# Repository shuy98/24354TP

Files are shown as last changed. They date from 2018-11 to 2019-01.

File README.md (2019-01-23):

# Semi-Autonomous Omnidirectional Manipulation Robot 
Term project for course 24-354 Gadgetry: Sensors, Actuators, and Processors at Carnegine Mellon University.  
This is a team project by Shu You, Nikhila Vembu, and Hardik Singh.  
Any questions/comments or you want additional info please send me an email: shuy@andrew.cmu.edu 

## Description
We created a small, moveable, omnidirectional robot that will be controlled virtually using a Kinect. We will demonstrate control of the robot and the ability to accomplish a terrain manipulation task with the robot by using a series of arm/hand gestures to command the robot’s movement and use of its gripper. The task will consist of retrieving an object and returning it into and ending spot based on the way we direct it with our bodies. The robot will ideally have to navigate through a few obstacles and then reach a box which senses that the robot arrived with the object.

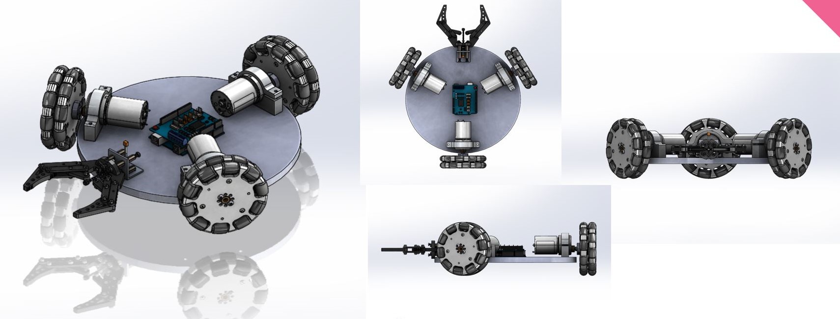
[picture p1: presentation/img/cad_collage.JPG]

*Fig 1. Robot CAD Image*

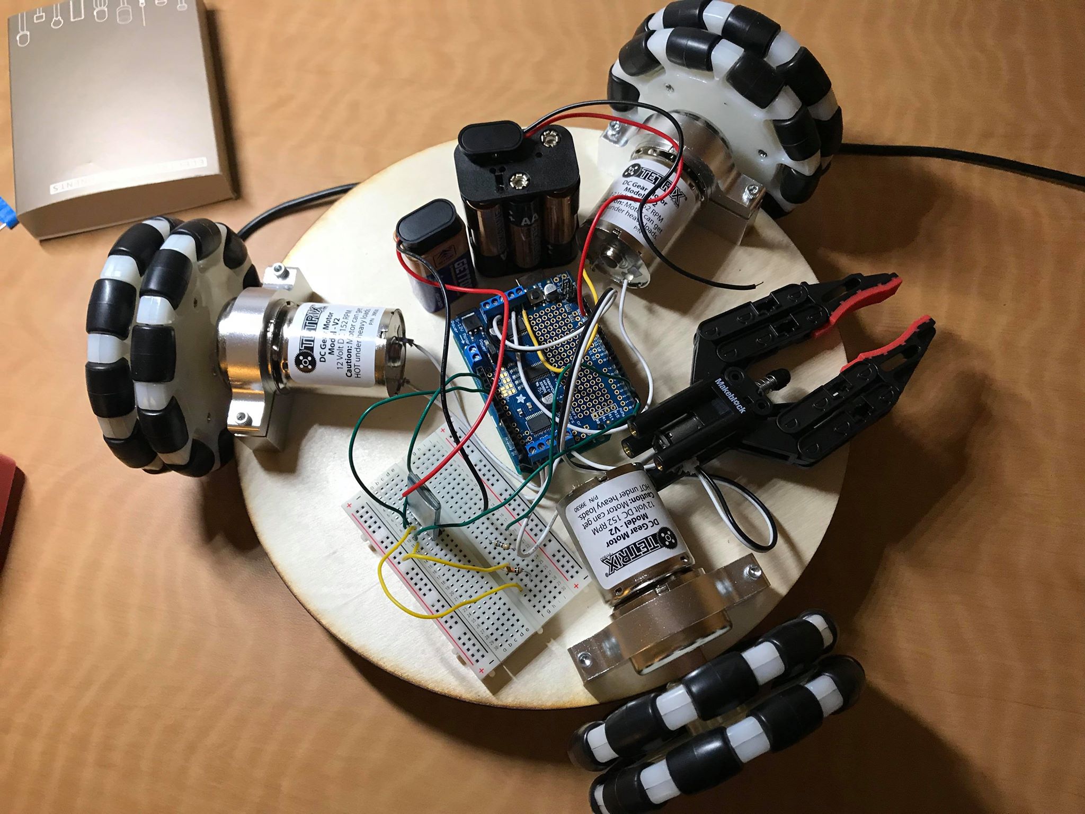
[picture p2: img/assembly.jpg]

*Fig 2. Robot Final Assembly*

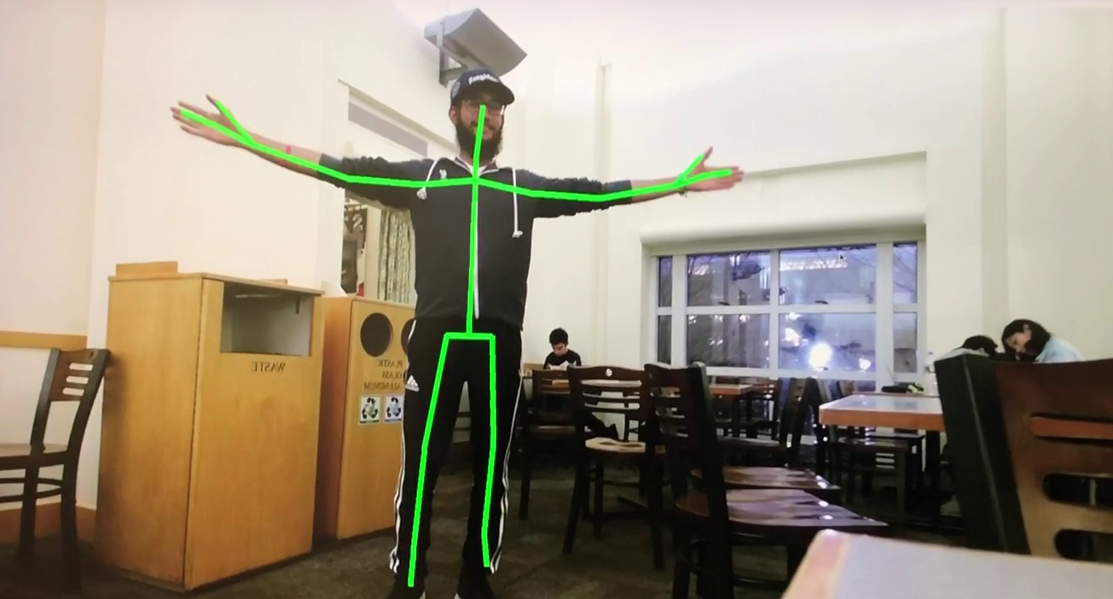
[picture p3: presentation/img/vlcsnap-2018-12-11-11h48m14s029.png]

*Fig 3. Kinect Control Interface*

## Problem Statement
We are aiming to display and test how well we can control unmanned robots and drones better with our bodies. 
Where "gaming controllers" are limited by their buttons, we can move our body more precisely and in a greater variety of ways, giving us access to improved ways of controlling the robot.

## Electronic Components
- Microprocessors 
  - Two Arduino UNO
- Actuators 
  - Three DC motors
  - One gripper with DC motor
- Sensors
  - Two Elegoo HC-SR04 proximity sensors
  - Microsoft Kinect

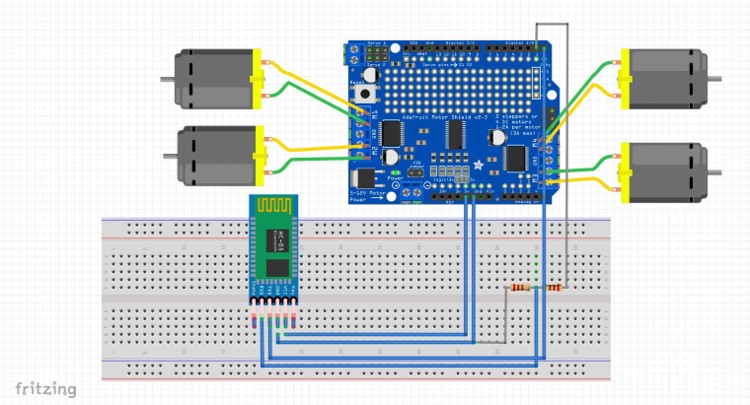
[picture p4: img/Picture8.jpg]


*Fig 4. Main Circuit Schematics*
  
## Kinect
Read body joints and save in (x, y, z) coordinates. Do calculations based on joints coordinates.
  
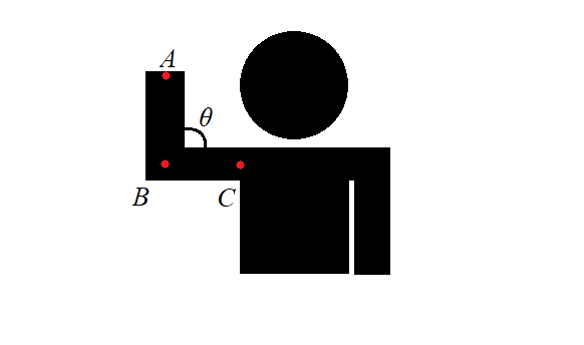
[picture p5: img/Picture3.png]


*Fig 5. Gesture diagram*

- Take (x, y) coordinates of points A, B, and C.
- Use Pythagorean Theorem to calculate AB and BC.
- Use dot product to calculate the angle θ.
- We designed 8 gestures.

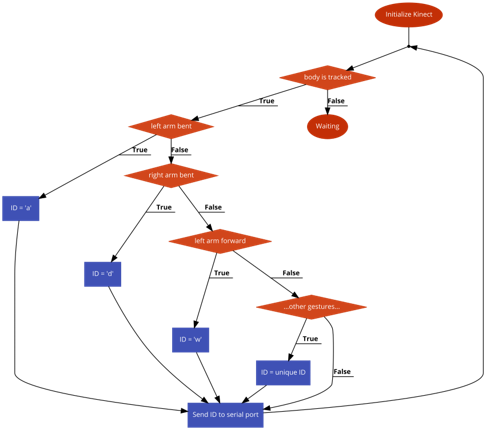
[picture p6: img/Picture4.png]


*Fig 6. Kinect Code Flowchart*

Kinect reads gesture and maps the gesture to a unique ID, then it sends the ID to serial port. 

## Robot Design and Motion Design

We used balsa wood as the base plate and we used laser cutter to cut the plate. We also chose omniwheels to allow the robot to move and rotate in any directions. A small DC motor equipped gripper is integrated to the robot, so it can pick up objects.

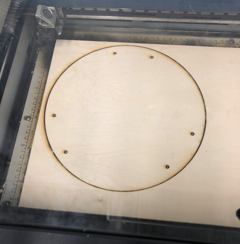
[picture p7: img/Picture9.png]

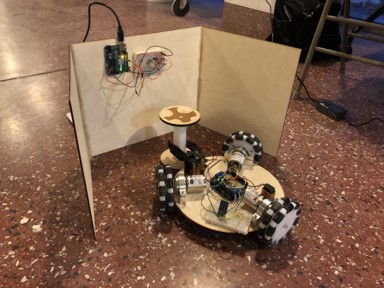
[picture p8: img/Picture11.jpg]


*Fig 7. Robot design process and robot picking up object*

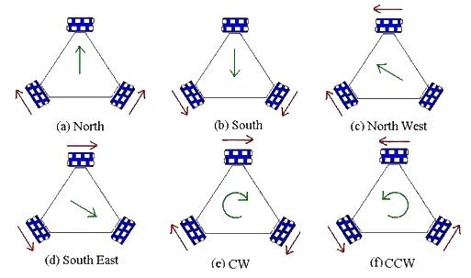
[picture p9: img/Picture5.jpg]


*Fig 8. Robot Motion Diagram*

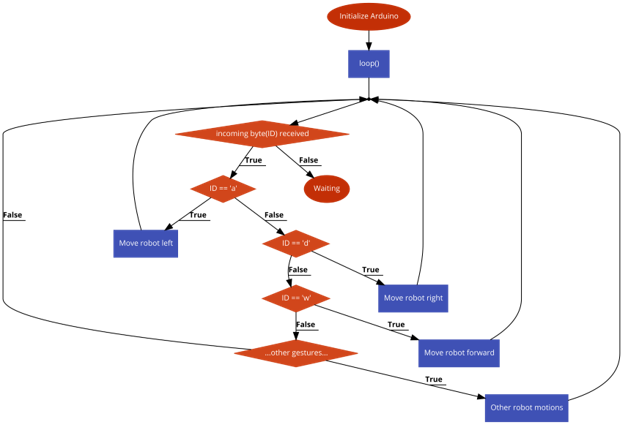
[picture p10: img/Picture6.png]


*Fig 9. Robot(Arduino) Code Flowchart*

Robot motion is based on different spinning speeds of three DC motors. For example, if we want the robot to move forward, we spind left wheel forward and right wheel backward while keeping the third wheel fixed.

- Arduino reads ID from serial port. 
- Maps ID to a specific motion helper function (e.g. moveForward()).
- Execute motion and wait for next incoming ID.
- 8 gestures map to 8 motions.

## Video Demo on Wirelessly Control the Robot
https://drive.google.com/file/d/1rcVZQeMSRfaizCOLsIZgg6IILubUMUVS/view?usp=sharing  

Interesting short progress demo videos:  
https://drive.google.com/drive/folders/1GpftXtcF17ZE3UGAxnW7FcvbJkevERj8?usp=sharing

## Additional Info
Check project proposal and project progress reports for more details.  
Project Proposal: https://github.com/shuy98/24354TP/blob/master/Project%20Proposal.pdf  
Progress 1 report: https://github.com/shuy98/24354TP/blob/master/Progress%20Update%201-2.pdf  
Progress 2 report: https://github.com/shuy98/24354TP/blob/master/Progress%20Update%202.pdf

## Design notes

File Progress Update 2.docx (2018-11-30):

Omnidirectional Unmanned Manipulation Robot with Kinect Control

Progress Update 2

December 1st, 2018

Summary

In this progress update, we will show you the mechanics of our first prototype of the robot. We will also show you a working circuit that controls three DC motors and a gripper, as well as a circuit that utilizes an ultrasonic proximity sensor to control an LED. In addition, we will present code snippet for Arduino board, which controls the motors, and the code for Kinect, which reads human gesture and communicates with Arduino board. Finally, we will discuss the issue we encountered so far and things to be done before final presentation.

1) Mechanics

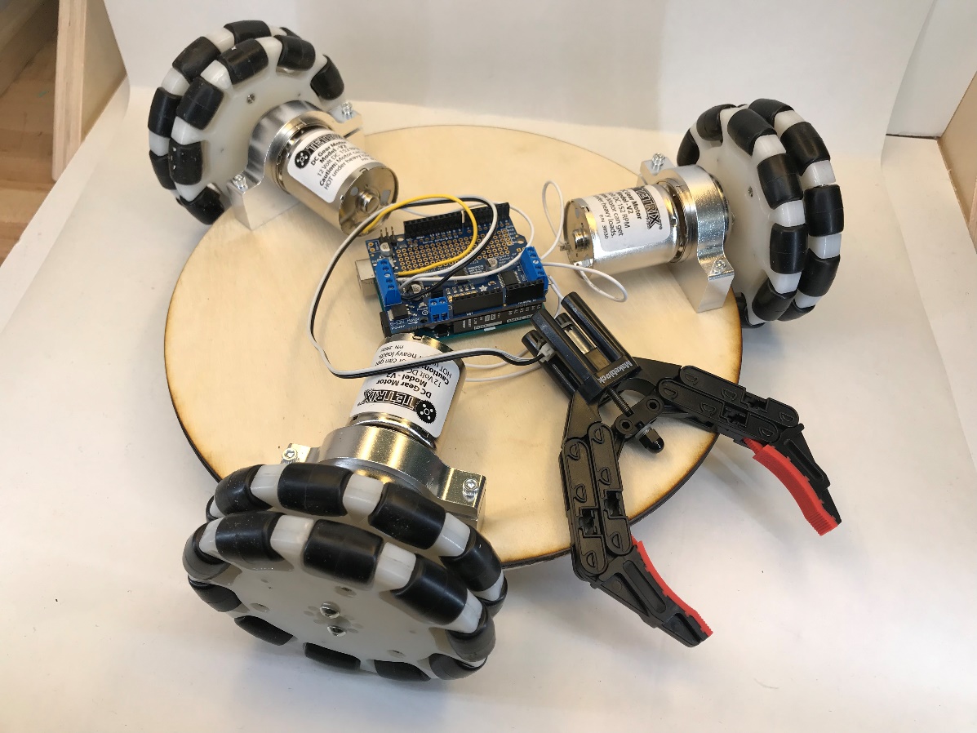
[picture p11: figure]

Figure 1: Isometric View of the Robot Assembled

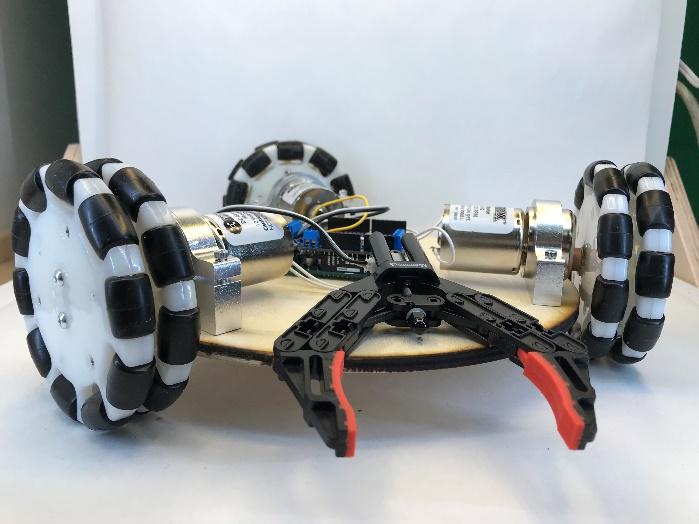
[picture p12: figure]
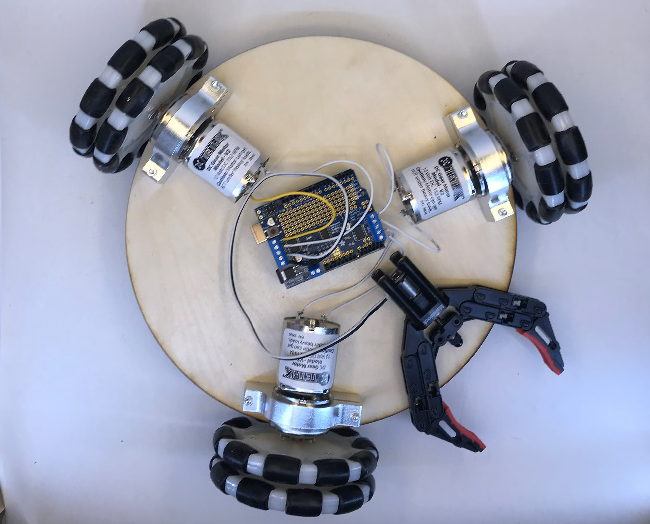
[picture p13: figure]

Figure 2: Side and Top View of the Robot Assembled

We require the center plate to be able to hold the motor-wheel sets and it should be light weight. That’s why we chose 6mm thick wood as the material for the center plate. In addition, we can use laser cutter to easily modify the shape of the wood plate.

Figure 3: Laser-cutting the Center Plate

We used a metal DC motor mount to secure the motor-wheel set on the plate. The motor mount we used is thick and sturdy enough to ensure that the motors are inline with the plate.

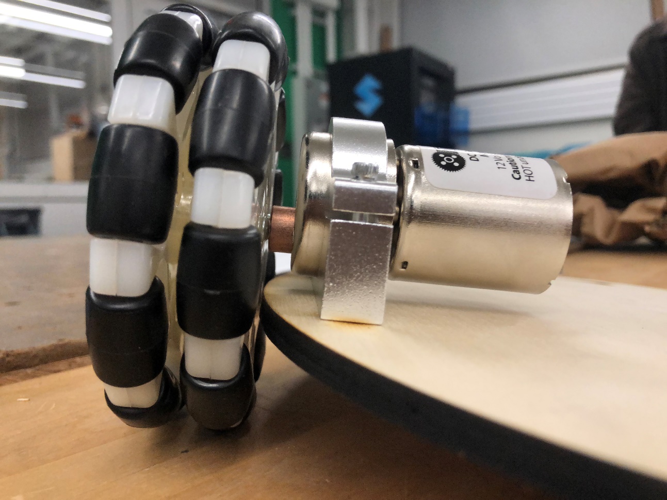
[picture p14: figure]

Figure 4: Motor Mount Side View

2) Electronics

Video demo is placed at the end of section 3) Code. For main body of the robot, we used one Arduino UNO and an Adafruit Motor Shield. We have three wheels connected to three DC motors and one gripper, which is also connected to a small DC motor.

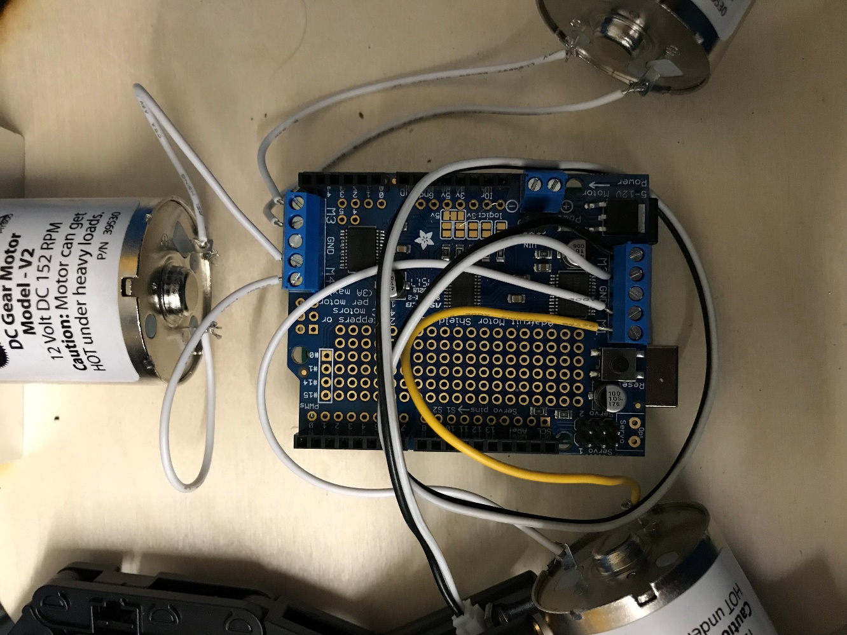
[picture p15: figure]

Figure 5: Wheels and gripper working circuit

One Adafruit motor shield supports at most 4 DC motors, so we used M1, M3, and M4 for the DC motors for wheels, and M2 for the gripper. The DC motors for wheels support 5V to 12V voltage. It has free spin RPM of 152, and stall torque of 2.25Nm. Even though we are powering the motors using 9V voltage, they can provide enough torque and speed to the entire robot, which we estimated to be no heavier than 2.5Kg.

The gripper is equipped with an N20 DC gear motor to allow the gripper to open and close.

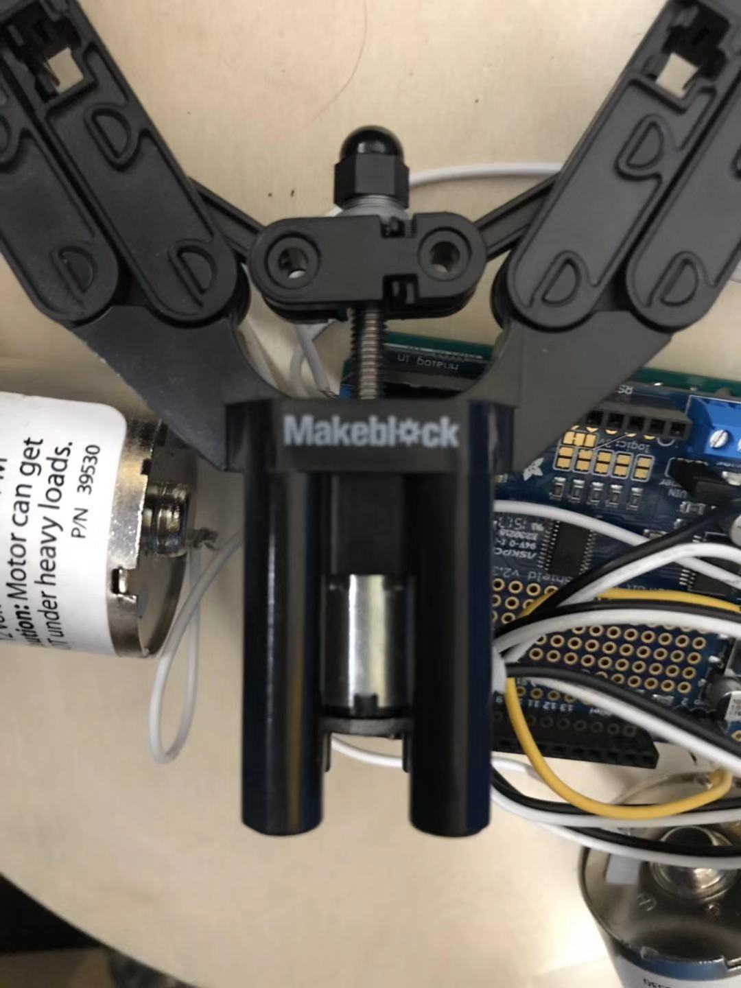
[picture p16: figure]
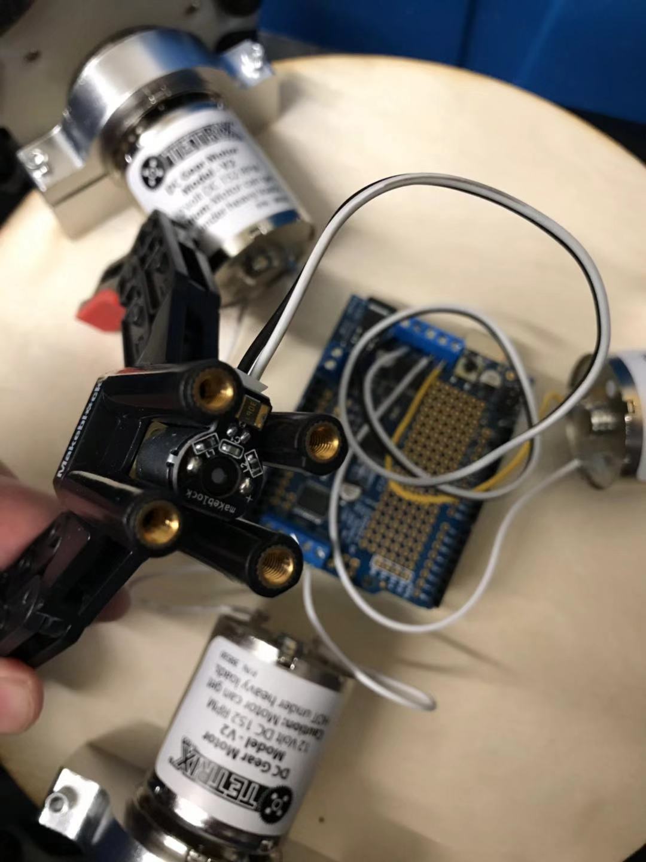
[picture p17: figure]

Figure 6: DC gear motor

3) Code

This time, we developed Arduino code to control three DC motors and python code to allow Kinect to send human gesture signal to Serial port of Arduino. We created a GitHub repo to help us manage the version of the code and allow us to collaborate easily. Link: https://github.com/shuy98/24354TP

(Comprehensive source code for Arduino can be found using the following link: https://github.com/shuy98/24354TP/tree/master/progress_2)

We used Adafruit motor shield library to control DC motors. Since we are using three DC motors for wheels and one DC motor for gripper, we initialized all these four motors.

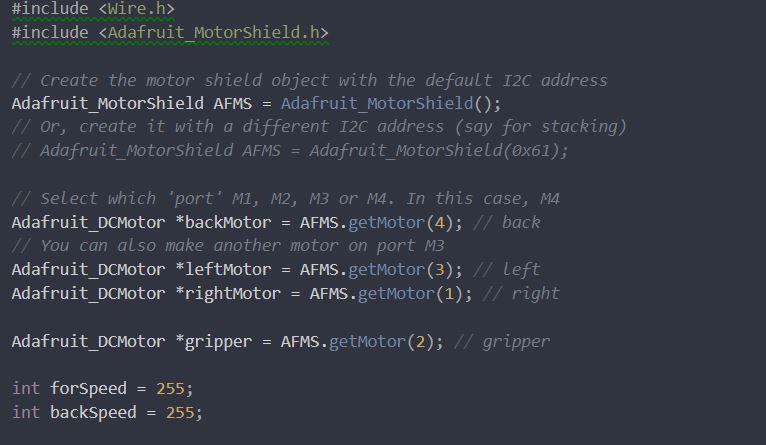
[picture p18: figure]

Figure #: Initialize DC motors from Adafruit Motor library

In this loop, it actively listens for signal from Serial port (Kinect interface sends signal to the Serial port). If Arduino receives the signal and it matches the condition, in this case it’s character ‘f’, it will turn on the motor. We turn three motors in the same direction to make the robot turn clockwise/counter-clockwise. To make it move forward and backward, we fix the back wheel and turn the other two of the wheels in opposite directions.

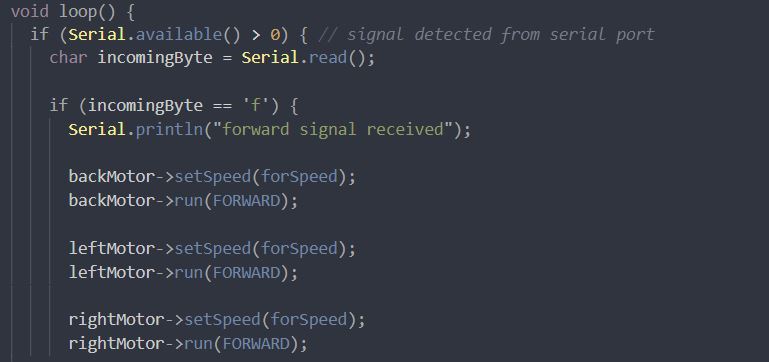
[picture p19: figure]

Figure #: Listen for signal and turn on the motor

We didn’t make any major changes to the Kinect side code except some modularity improvements, details have been discussed in progress update 1. Check out the source code from this link: https://github.com/shuy98/24354TP/blob/master/run.py

Using this code, we were able to instruct the robot using Serial port and allow it to move forward, backward, and turn clockwise/counter-clockwise.

Video demo:

- Robot moving forward and backward. https://drive.google.com/file/d/1mRkVVeUIwBoWFXJ1S_hFO90CJ1UFN2j4/view?usp=sharing
- Robot turning clockwise/counter-clockwise https://drive.google.com/file/d/1EuiUJG095ITJh76e2yqfx4a8CCoWp9M_/view?usp=sharing
- Gripper open and close to grip an object https://drive.google.com/file/d/1xRY6WJ7tjuOVHeXRk6lLYwNfiMLbZ2xo/view?usp=sharing

4) Reflections

One unexpected issue we encountered in this prototype assembly is that a single 9V battery does not have enough energy to drive three large 12V DC motors and one small DC motor simultaneously. It’s not an issue if we power the motor shield using the cable, which draws current either from USB port or power outlet. However, since we will make the robot wireless (remote control) eventually, we have to find a way to power these motors with batteries. Therefore, we are considering using six 1.5V AA battery pack, which will provide 9V in total to power the motor shield. For the Arduino UNO itself, we will keep using a single 9V battery since it only powers one single Bluetooth module, which does not draw much energy compared with four DC motors.

One expected issue is that the robot does not move perfectly straight in forward and backward motion. Possible solutions are:

- Add weight to one side to make the robot balanced.
- Tweak the speed of the DC motors.
- Mechanical changes on the structure.

Things to be done before Demo day:

- Address the issues mentioned above.
- Incorporate a Bluetooth module to allow remote control.
- Gripper attachment mechanical design.
- Kinect gesture design.
- Pizzazz

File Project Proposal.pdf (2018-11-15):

## Omnidirectional Unmanned Manipulation Robot with Kinect Control

Project Proposal

October 30, 2018

1) Team member names and roles
Team Member | Specialization | Group-wide Roles
Nikhila Vembu | - Solidworks design - Prototyping | - Major Project Decisions - Putting things together - Helping with all tasks - Testing
Shu You | - Kinect/Arduino interfacing - Circuitry design
Hardik Singh | - Robot base design/assembly - Body analysis algorithm
2) Problem you are trying to solve and why it is interesting. What will you demonstrate on demo day?

Identified Problem

Buttons are of the past. Controllers can limit how exactly you can control a moving part; buttons are not exactly intuitive for 3 dimensional control. Hence, we want to try controlling a robotic platform using our entire bodies, through a kinect. This could be helpful in search and rescue missions, factory settings to increase safety, and much more. Woooo autonomous control!!

Our solution

We are creating a small, moveable, omnidirectional robot that will be controlled virtually using a Kinect. On the demo day, we will demonstrate control of the robot and the ability to accomplish a terrain manipulation task with the robot by using a series of arm/hand gestures to command the robot’s movement and use of its 4-bar linkage gripper. Upon of accomplishing the task, the robot will show some Pizazz(a surprise!!).

The task will consist of retrieving an object and returning it into and ending spot based on the way we direct it with our bodies. The robot will ideally have to navigate through a few obstacles and then reach a box which senses that the robot arrived with the object.

3) Course topics that will be used. What sensors and actuators will you use? What will your code do?
- Actuators
- Servo motors (x4)
- Sensors
- Proximity Sensor
- Kinect
- Processor
- Arduino Uno (x2)

Our code will be designed to take input from the kinect in the form of body-part locations and joint angles. From there, our code will be convert body movements into commands for the omnidirectional base. We will also have a separate setup where the proximity sensor will be running an open loop system where as soon as the omnidirectional base moves within range, the setup lights up to mark a completion of the task.

4) What materials you foresee needing to complete the project? What makerspace resources will you need access to?

Materials List

1. Omnidirectional Robot wheels x4 (1 backup)
2. Bearings x6 (2 backup)
3. Proximity sensor (Upto 3, depending on budget)
4. Light but strong wood (potentially balsa)
5. Acrylic Sheets
6. Servo Motors (x6) (2 backups)
7. Extra Wires / Breadboard / Electronics

Makerspace resources

- MakerSpace computers for SolidWorks
- Laser Cutters
- 3D Printers
- Assembly space

5) Project timeline. What do you anticipate completing by the progress update points?

Progress Update 1 (Nov 13th)

- Software proof of interfacing between kinect and arduino
- Simple minimal circuit - evidence of interfacing (lights turn on from person movement)
- Circuit schematics
- Sketches of robot design and photos of anything we’ve done so far
- Solidworks model for Omnidirectional Robot
- Body control algorithms
- Reflection of Progress

Progress Update 2 (Nov 27th)

- Working/moving Omnidirectional Robot
- Functioning 4-bar linkage gripper on the robot
- Primarily working on figuring out tweaks for controlling the robot and creating the final stand which lights up upon completion.

Note: We’re not sure how Thanksgiving Break will affect this - we hope to complete these tasks but may be 2-3 days behind if we can’t get what we want done over Thanksgiving Break.

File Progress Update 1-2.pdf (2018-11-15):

## Omnidirectional Unmanned Manipulation Robot with Kinect Control

Progress Update 1

November 14, 2018
Summary

The primary goals for project update 1 that we detailed in the project proposal were to determine the compatibility and feasibility of our different hardwares and softwares, to order all the parts we would require for our robot, and to create models/diagrams detailing how the hardware and circuits would come together. Overall, we we were successful in achieving all these goals, and are confident that our project is both feasible and achievable. Though we have not had to make major changes to our project scope from what we initially envisioned, small changes here and there have helped guide our project in our desired direction.
1) Detailed Project Description

Mechanics

- We will be using the following components to assemble our robot:
- From TETRIX, 3 pieces of each:
- DC Motor
- Motor Mount
- Motor Shaft Hub
- 4’’ Omni Wheels
- Balsa / Plywood that we can laser cut into shape
- MakeBlock Gripper
- Custom L-Bracket
- Arduino Uno
- Arduino Motor Shield

The following figures present a mockup of what our robot will look like, when assembled.

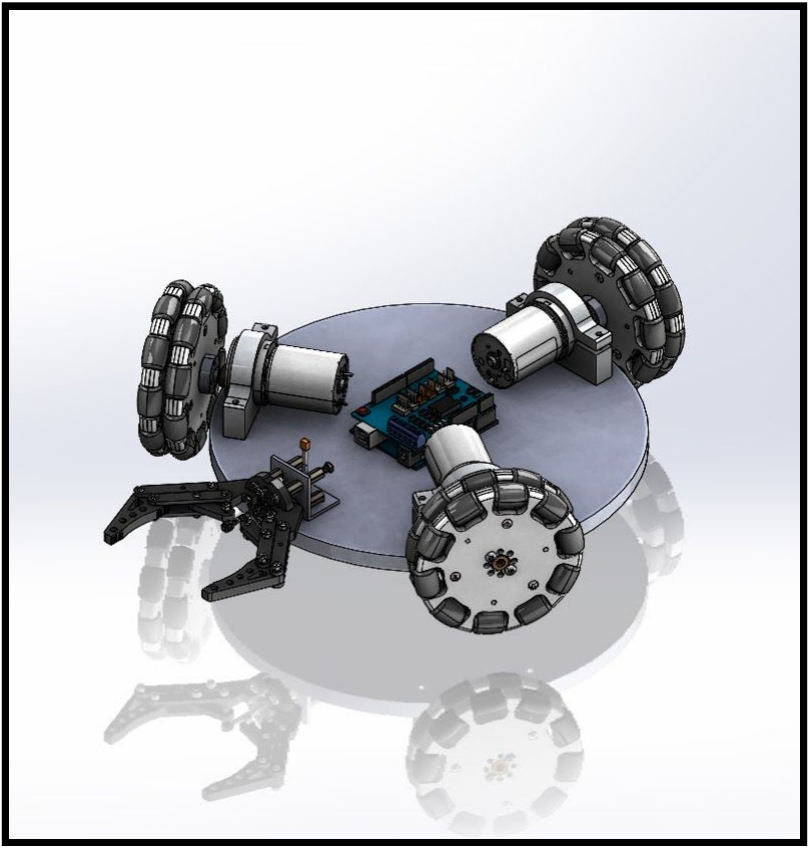
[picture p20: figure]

Figure 1: Isometric View of the Robot Assembled

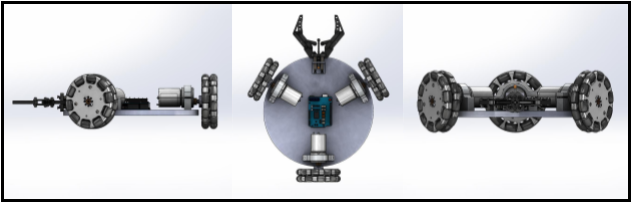
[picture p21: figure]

Figure 2: Isometric View of the Robot Assembled

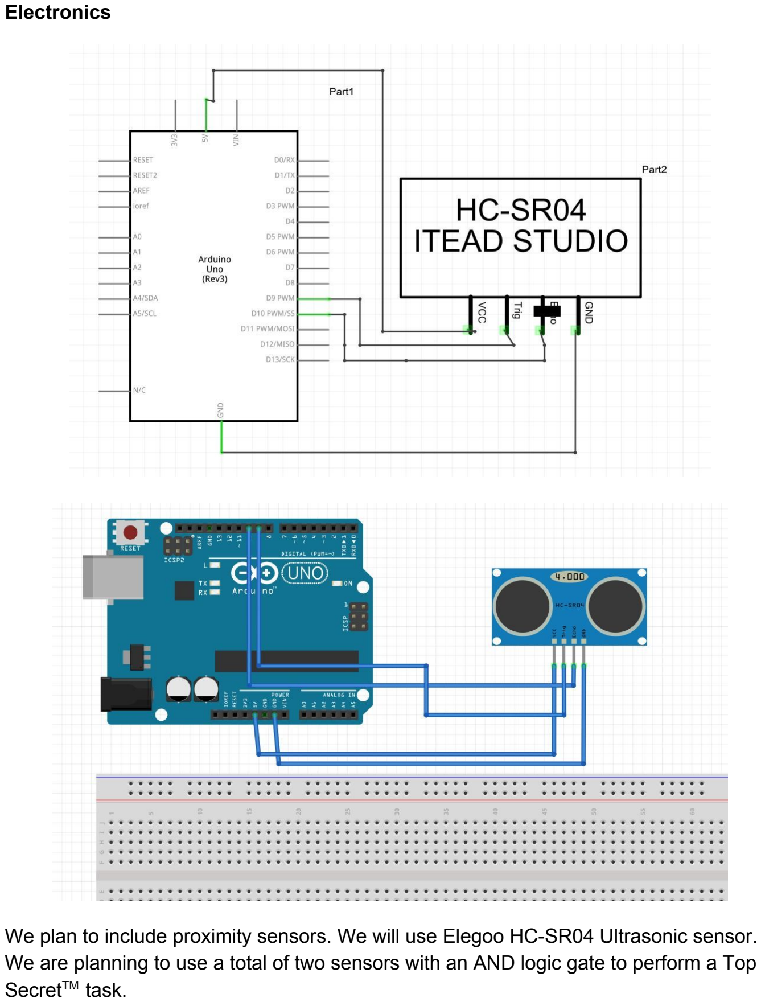
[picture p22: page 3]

Electronics

We plan to include proximity sensors. We will use Elegoo HC-SR04 Ultrasonic sensor. We are planning to use a total of two sensors with an AND logic gate to perform a Top SecretTM
task.

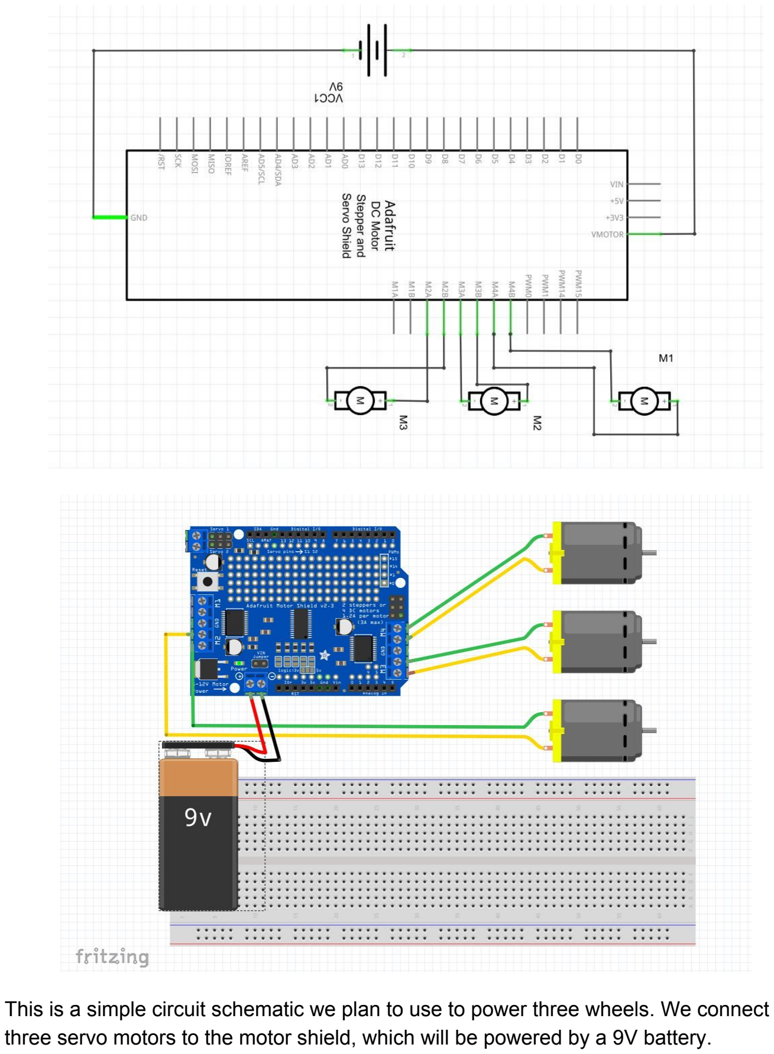
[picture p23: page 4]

This is a simple circuit schematic we plan to use to power three wheels. We connect three servo motors to the motor shield, which will be powered by a 9V battery.

Code / Software

In this section, we will demonstrate the code we will use in this project. This sections includes two flow charts that demonstrate the general idea of the code. We also created an additional demo to show you how it really works.

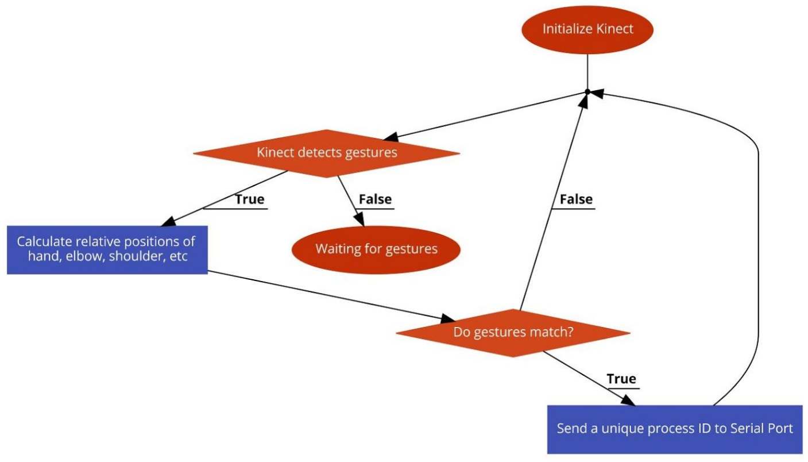
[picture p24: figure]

Figure 3: Kinect code flow chart

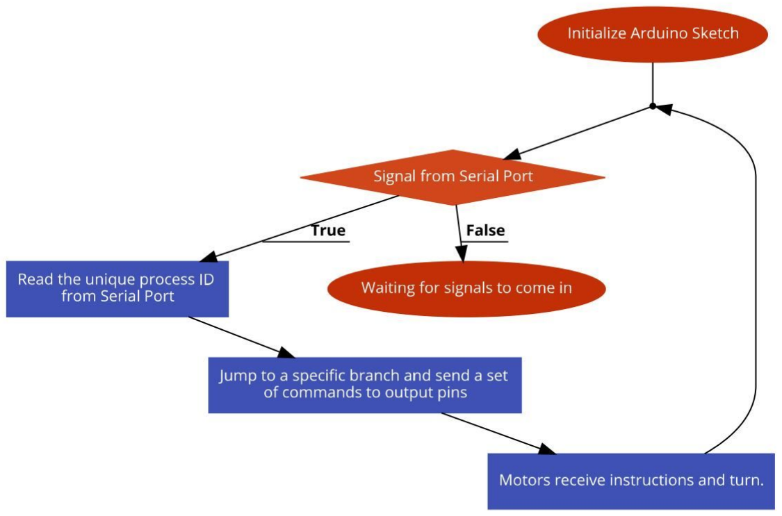
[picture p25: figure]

Figure 4: Arduino code flow chart

To better demonstrate how this code works, we prepared a short demo.

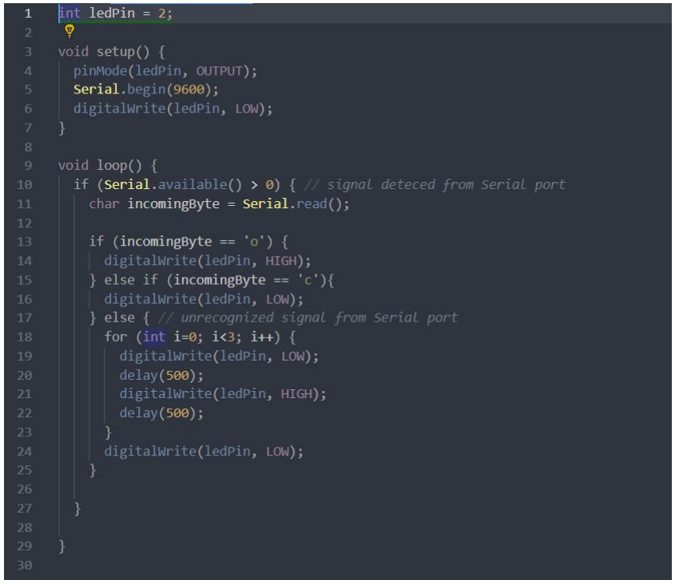
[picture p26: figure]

This is the Arduino code demo. The loop running constantly and waiting for the signal from serial port. Once it detects signal, it checks whether the incoming signal is character ‘o’ (short for open) or character ‘c’ (short for close). If it’s ‘o’, it will write HIGH to output pin, which is connected to an LED. As a result, LED will light up. (Code could be found at: https://github.com/shuy98/24354TP/tree/master/progress_1)

Below is Kinect code demonstration. In this demo, I’m using left arm as an example. When I bend my arm and the angle is less than 90 degrees, it will send a unique ID (a character in this case) to serial port. When arduino receives that ID, the LED connected to Arduino will light up. Otherwise, it will send a different ID to serial port and Arduino will turn the LED off.

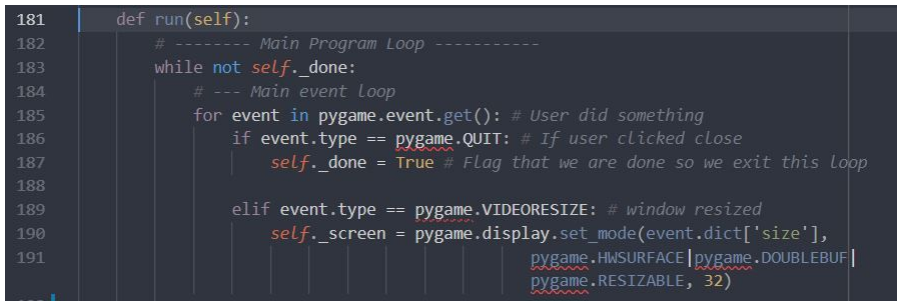
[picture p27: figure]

This is the main loop that keeps the Kinect running. It will wait for gestures to come in.

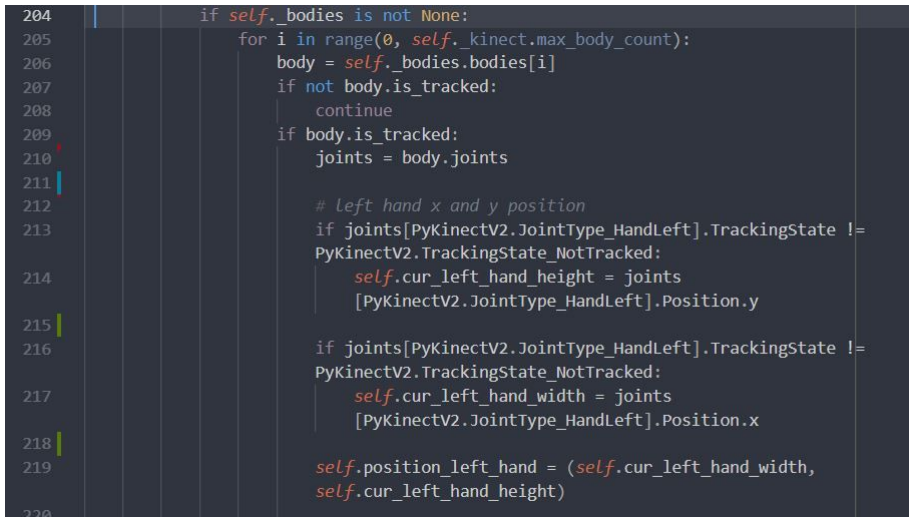
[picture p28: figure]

When a gesture is detected, it stores the positions of the joints into variables.

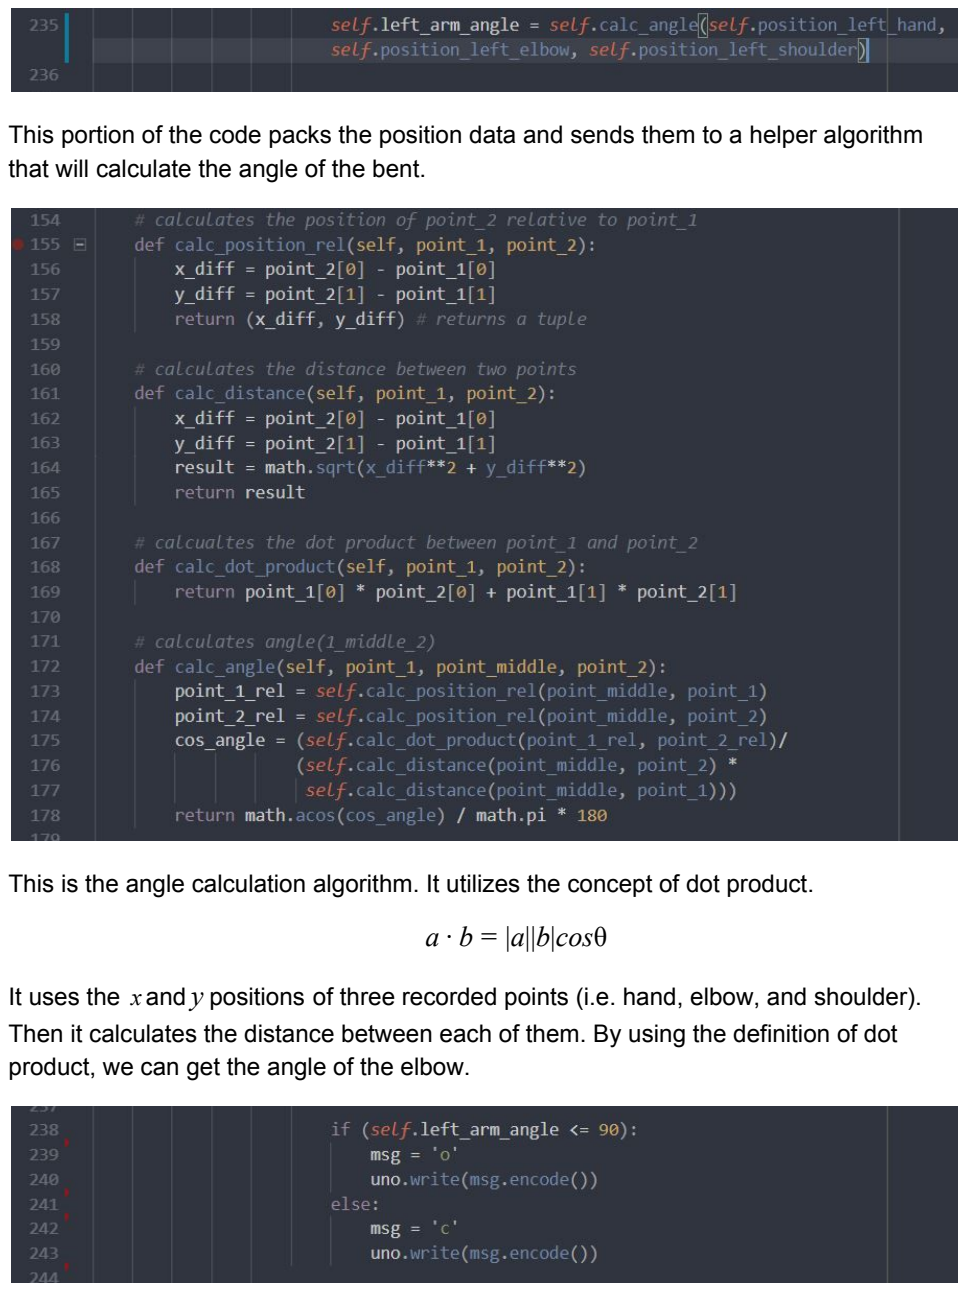
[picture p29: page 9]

This portion of the code packs the position data and sends them to a helper algorithm that will calculate the angle of the bent.

This is the angle calculation algorithm. It utilizes the concept of dot product.
a · b = |a||b|cosθ

It uses the x and y positions of three recorded points (i.e. hand, elbow, and shoulder). Then it calculates the distance between each of them. By using the definition of dot product, we can get the angle of the elbow.

Finally, it reads the angle of the elbow and sends the corresponding ID to serial port.

(Comprehensive code could be found at: https://github.com/shuy98/24354TP/blob/master/run.py)

We also did testing on both stepper motor and DC motor. Source file could be found at

https://github.com/shuy98/24354TP/tree/master/test_stepper

https://github.com/shuy98/24354TP/tree/master/DCMotorTest

Two video demos:

https://drive.google.com/open?id=10e9v8KFh-VoghbmWhZYgv0whkZy-m0J-

https://drive.google.com/open?id=1bp5BivpgAqbur-f5CCS3yjhSytn4Ww5T

Reflections

- We definitely learned about how to choose the right motor - we had a lot of group discussions about this and have developed better intuition on the topic.
- We’re probably using up more of our budget than we want - if something breaks like a motor burning out or something, we don’t have too much cushion with our remaining budget which is a risk that we are taking.
2) Issues Encountered

Most of the issues we encountered revolved around finding components of the robot which were compatible with each other. There were two major compatibility tests that we had to make. The first was to see if we could control a motor from a Kinect by interfacing through an Arduino. As displayed in the videos linked in Code/Software section, we were able to get things working by interacting with the Arduino through a Serial port. Our second major compatibility test was that we find a motor that could fulfill our expected torque requirements, but also be compatible with our wheels without us having to create any adaptors. This was an issue primarily because it took up a lot of time - we had to keep searching for new motors of different companies and setups to see what would fit our requirements the best. We ended up going with TETRIX motors, as they also sell adaptors for the motors to their omnidirectional wheels, and even have available a motor mount, making our lives a lot easier.
3) Proposed Changes to Project Scope

Overall, we haven’t had to change our project scope too much. The biggest change is probably the fact that our gripper is no longer attached to our robot using a 4 bar linkage. This is because we ultimately deemed it an unnecessary complication. We will instead be creating a simple shape with styrofoam. This shape will be placed at a slight height, allowing the gripper to simply close around it and then have the robot move without dragging the object on the floor.

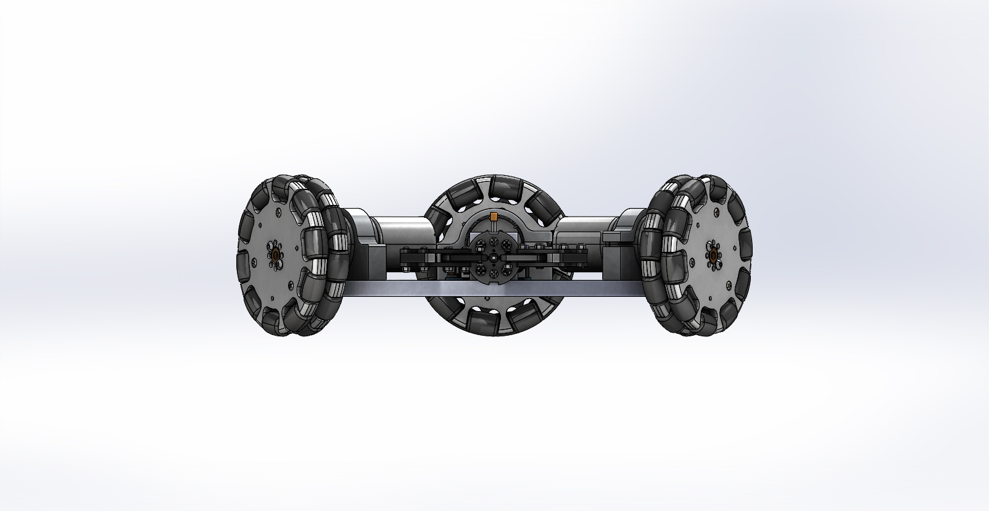
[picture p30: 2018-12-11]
presentation/img/Angle_2.JPG

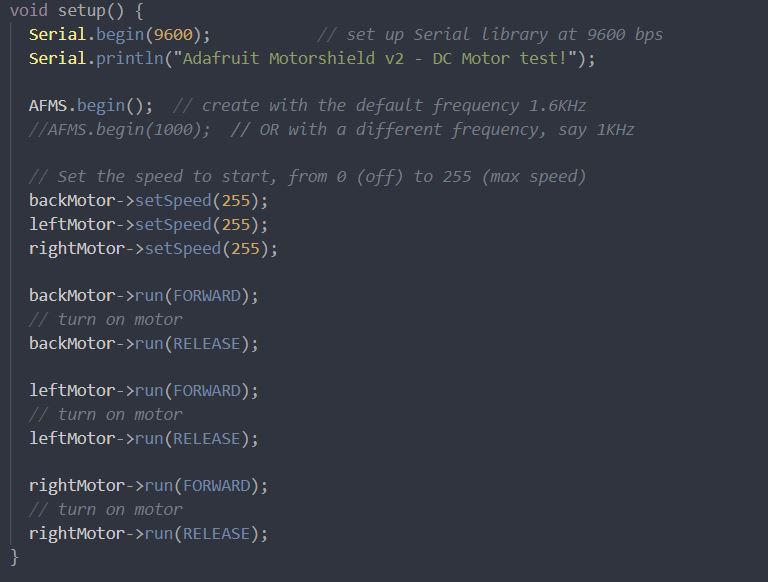
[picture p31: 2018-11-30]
img/Capture_2.JPG

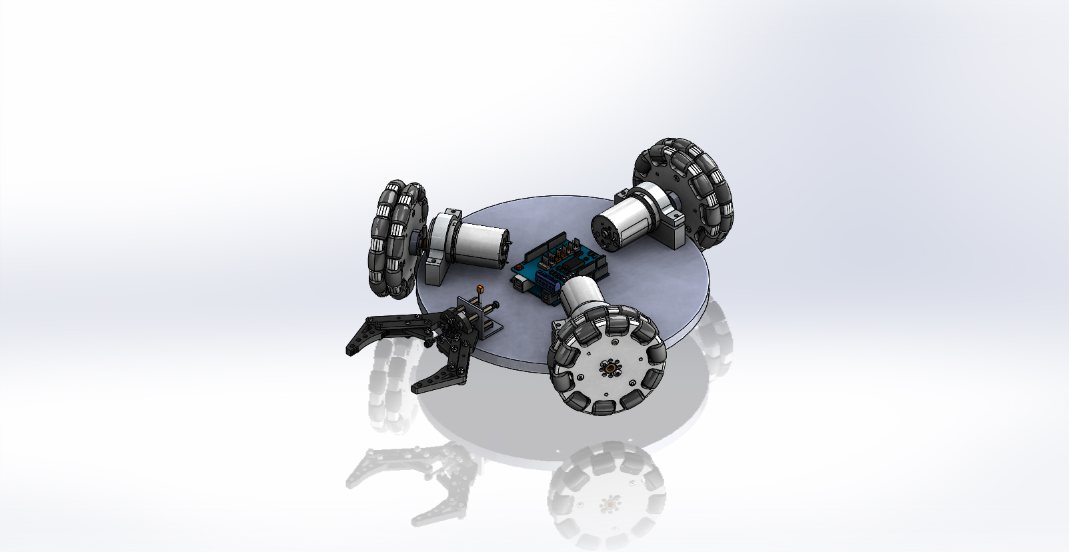
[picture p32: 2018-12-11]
presentation/img/Angle_1.JPG

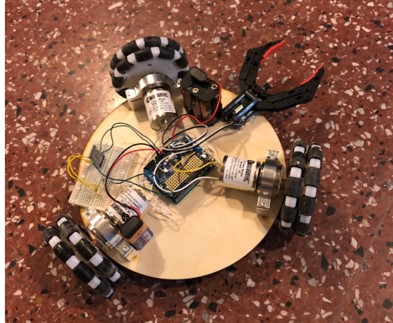
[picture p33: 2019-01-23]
presentation/img/Picture1.jpg

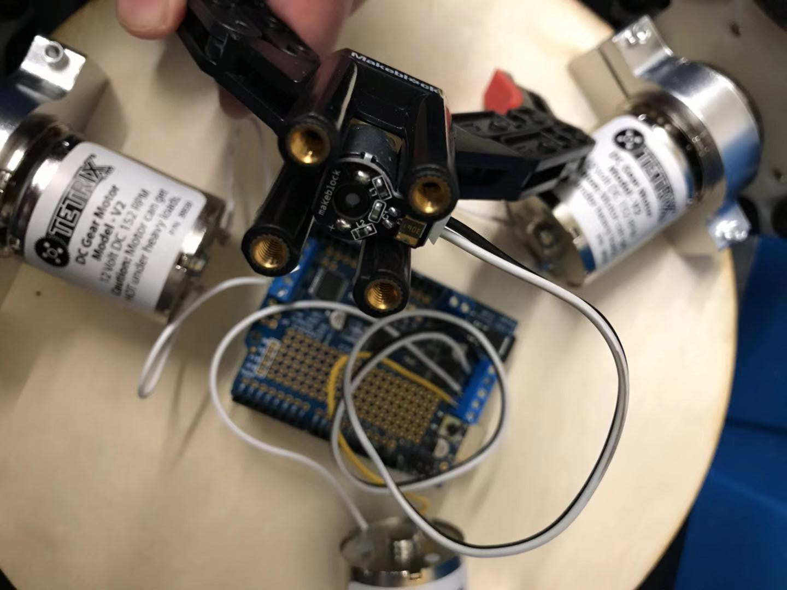
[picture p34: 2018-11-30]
img/微信图片_20181130164040.jpg

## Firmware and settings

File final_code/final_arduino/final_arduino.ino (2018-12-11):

#include <Wire.h>
#include <Adafruit_MotorShield.h>
#include <math.h>

// Create the motor shield object with the default I2C address
Adafruit_MotorShield AFMS = Adafruit_MotorShield(); 
// Or, create it with a different I2C address (say for stacking)
// Adafruit_MotorShield AFMS = Adafruit_MotorShield(0x61); 

// Select which 'port' M1, M2, M3 or M4. In this case, M4
Adafruit_DCMotor *backMotor = AFMS.getMotor(4); // back
// You can also make another motor on port M3
Adafruit_DCMotor *leftMotor = AFMS.getMotor(3); // left
Adafruit_DCMotor *rightMotor = AFMS.getMotor(1); // right
Adafruit_DCMotor *gripper = AFMS.getMotor(2); // gripper

/* global variables */
int forSpeed = 92;
int backSpeed = 92;
int gripperSpeed = 192;
int turnSpeed = 36;

/* function prototypes */
void turnCCW();
void terminate();
void turnCW();
void moveForward();
void moveBackward();
void closeGripper();
void openGripper();
void moveRight();
void moveLeft();

void setup() {
  Serial.begin(9600);           // set up Serial library at 9600 bps
  Serial.println("Adafruit Motorshield v2 - DC Motor test!");

  AFMS.begin();  // create with the default frequency 1.6KHz
  //AFMS.begin(1000);  // OR with a different frequency, say 1KHz 
}

void loop() {
  if (Serial.available() > 0) { // signal detected from serial port
    char incomingByte = Serial.read();

    if (incomingByte == 'l') { // turn counter-clockwise
      turnCCW();

    } else if (incomingByte == 't') { // terminates
      terminate();

    } else if (incomingByte == 'r') { // turn clockwise
      turnCW();
      
    } else if (incomingByte == 'w') { // move forward
      moveForward();

    } else if (incomingByte == 's') { // move backward
      moveBackward();

    } else if (incomingByte == 'c') { // close gripper
      closeGripper();

    } else if (incomingByte == 'o') { // open gripper
      openGripper();

    } else if (incomingByte == 'd') { // move right
      moveRight();

    } else if (incomingByte == 'a') { // move left
      moveLeft();

    } else { // unrecognized signal from Serial port
      Serial.println("unknown signal received");
    }
  } 
}

void turnCCW() {
  backMotor->setSpeed(turnSpeed);
  backMotor->run(BACKWARD);
  
  leftMotor->setSpeed(turnSpeed);
  leftMotor->run(BACKWARD);
  
  rightMotor->setSpeed(turnSpeed);
  rightMotor->run(BACKWARD);
}

void terminate() {
  backMotor->run(RELEASE);
  leftMotor->run(RELEASE);
  rightMotor->run(RELEASE);
  gripper->run(RELEASE);
}

void turnCW() {
  backMotor->setSpeed(turnSpeed);
  backMotor->run(FORWARD);
  leftMotor->setSpeed(turnSpeed);
  leftMotor->run(FORWARD);
  rightMotor->setSpeed(turnSpeed);
  rightMotor->run(FORWARD);
}

void moveForward() {
  leftMotor->setSpeed(backSpeed);
  leftMotor->run(FORWARD);
  rightMotor->setSpeed(forSpeed);
  rightMotor->run(BACKWARD);
}

void moveBackward() {
  rightMotor->setSpeed(backSpeed);
  rightMotor->run(FORWARD);
  leftMotor->setSpeed(forSpeed);
  leftMotor->run(BACKWARD);
}

void moveRight() {
  rightMotor->setSpeed(forSpeed/2);
  rightMotor->run(FORWARD);
  leftMotor->setSpeed(forSpeed/2);
  leftMotor->run(FORWARD);

  backMotor->setSpeed(forSpeed/2*(pow(3, 0.5)));
  backMotor->run(BACKWARD);  
}

void moveLeft() {
  rightMotor->setSpeed(backSpeed/2);
  rightMotor->run(BACKWARD);
  leftMotor->setSpeed(backSpeed/2);
  leftMotor->run(BACKWARD);

  backMotor->setSpeed(backSpeed/2*(pow(3, 0.5)));
  backMotor->run(FORWARD);  
}

void closeGripper() {
  gripper->setSpeed(gripperSpeed);
  gripper->run(BACKWARD);
}

void openGripper() {
  gripper->setSpeed(gripperSpeed);
  gripper->run(FORWARD);
}

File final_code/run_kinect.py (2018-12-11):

#################################
# Kinect body detection
# from https://github.com/Kinect/PyKinect2
# adapted and modified by Shu You
#################################

from pykinect2 import PyKinectV2
from pykinect2.PyKinectV2 import *
from pykinect2 import PyKinectRuntime

import ctypes
import _ctypes
import pygame
import sys

import time
import math
import serial

if sys.hexversion >= 0x03000000:
    import _thread as thread
else:
    import thread

# colors for drawing different bodies 
SKELETON_COLORS = [pygame.color.THECOLORS["red"], 
                  pygame.color.THECOLORS["blue"], 
                  pygame.color.THECOLORS["green"], 
                  pygame.color.THECOLORS["orange"], 
                  pygame.color.THECOLORS["purple"], 
                  pygame.color.THECOLORS["yellow"], 
                  pygame.color.THECOLORS["violet"]]

uno = serial.Serial('COM12', 9600) # enter serial port number here

class BodyGameRuntime(object):
    def __init__(self):
        pygame.init()

        # Used to manage how fast the screen updates
        self._clock = pygame.time.Clock()

        # Set the width and height of the screen [width, height]
        self._infoObject = pygame.display.Info()
        self._screen = pygame.display.set_mode((self._infoObject.current_w >> 1, self._infoObject.current_h >> 1), 
                                               pygame.HWSURFACE|pygame.DOUBLEBUF|pygame.RESIZABLE, 32)

        pygame.display.set_caption("24354 Term Project Kinect")

        # Loop until the user clicks the close button.
        self._done = False

        # Used to manage how fast the screen updates
        self._clock = pygame.time.Clock()

        # Kinect runtime object, we want only color and body frames 
        self._kinect = PyKinectRuntime.PyKinectRuntime(PyKinectV2.FrameSourceTypes_Color | PyKinectV2.FrameSourceTypes_Body)

        # back buffer surface for getting Kinect color frames, 32bit color, width and height equal to the Kinect color frame size
        self._frame_surface = pygame.Surface((self._kinect.color_frame_desc.Width, self._kinect.color_frame_desc.Height), 0, 32)

        # here we will store skeleton data 
        self._bodies = None

        # left hand
        self.prev_left_hand_height = 0
        self.cur_left_hand_height = 0
        self.prev_left_hand_width = 0
        self.cur_left_hand_width = 0
        self.position_left_hand = (0, 0)

        # left shoulder
        self.prev_left_shoulder_height = 0
        self.cur_left_shoulder_height = 0
        self.prev_left_shoulder_width = 0
        self.cur_left_shoulder_width = 0
        self.position_left_shoulder = (0, 0)

        #left elbow
        self.prev_left_elbow_height = 0
        self.cur_left_elbow_height = 0
        self.prev_left_elbow_width = 0
        self.cur_left_elbow_width = 0
        self.position_left_elbow = (0, 0)

        #self.left_arm_angle = 0
        #self.is_calibrated = False


    def draw_body_bone(self, joints, jointPoints, color, joint0, joint1):
        joint0State = joints[joint0].TrackingState
        joint1State = joints[joint1].TrackingState

        # both joints are not tracked
        if (joint0State == PyKinectV2.TrackingState_NotTracked) or (joint1State == PyKinectV2.TrackingState_NotTracked): 
            return

        # both joints are not *really* tracked
        if (joint0State == PyKinectV2.TrackingState_Inferred) and (joint1State == PyKinectV2.TrackingState_Inferred):
            return

        # ok, at least one is good 
        start = (jointPoints[joint0].x, jointPoints[joint0].y)
        end = (jointPoints[joint1].x, jointPoints[joint1].y)

        try:
            pygame.draw.line(self._frame_surface, color, start, end, 8)
        except: # need to catch it due to possible invalid positions (with inf)
            pass

    def draw_body(self, joints, jointPoints, color):
        # Torso
        self.draw_body_bone(joints, jointPoints, color, PyKinectV2.JointType_Head, PyKinectV2.JointType_Neck)
        self.draw_body_bone(joints, jointPoints, color, PyKinectV2.JointType_Neck, PyKinectV2.JointType_SpineShoulder)
        self.draw_body_bone(joints, jointPoints, color, PyKinectV2.JointType_SpineShoulder, PyKinectV2.JointType_SpineMid)
        self.draw_body_bone(joints, jointPoints, color, PyKinectV2.JointType_SpineMid, PyKinectV2.JointType_SpineBase)
        self.draw_body_bone(joints, jointPoints, color, PyKinectV2.JointType_SpineShoulder, PyKinectV2.JointType_ShoulderRight)
        self.draw_body_bone(joints, jointPoints, color, PyKinectV2.JointType_SpineShoulder, PyKinectV2.JointType_ShoulderLeft)
        self.draw_body_bone(joints, jointPoints, color, PyKinectV2.JointType_SpineBase, PyKinectV2.JointType_HipRight)
        self.draw_body_bone(joints, jointPoints, color, PyKinectV2.JointType_SpineBase, PyKinectV2.JointType_HipLeft)
    
        # Right Arm    
        self.draw_body_bone(joints, jointPoints, color, PyKinectV2.JointType_ShoulderRight, PyKinectV2.JointType_ElbowRight)
        self.draw_body_bone(joints, jointPoints, color, PyKinectV2.JointType_ElbowRight, PyKinectV2.JointType_WristRight)
        self.draw_body_bone(joints, jointPoints, color, PyKinectV2.JointType_WristRight, PyKinectV2.JointType_HandRight)
        self.draw_body_bone(joints, jointPoints, color, PyKinectV2.JointType_HandRight, PyKinectV2.JointType_HandTipRight)
        self.draw_body_bone(joints, jointPoints, color, PyKinectV2.JointType_WristRight, PyKinectV2.JointType_ThumbRight)

        # Left Arm
        self.draw_body_bone(joints, jointPoints, color, PyKinectV2.JointType_ShoulderLeft, PyKinectV2.JointType_ElbowLeft)
        self.draw_body_bone(joints, jointPoints, color, PyKinectV2.JointType_ElbowLeft, PyKinectV2.JointType_WristLeft)
        self.draw_body_bone(joints, jointPoints, color, PyKinectV2.JointType_WristLeft, PyKinectV2.JointType_HandLeft)
        self.draw_body_bone(joints, jointPoints, color, PyKinectV2.JointType_HandLeft, PyKinectV2.JointType_HandTipLeft)
        self.draw_body_bone(joints, jointPoints, color, PyKinectV2.JointType_WristLeft, PyKinectV2.JointType_ThumbLeft)

        # Right Leg
        self.draw_body_bone(joints, jointPoints, color, PyKinectV2.JointType_HipRight, PyKinectV2.JointType_KneeRight)
        self.draw_body_bone(joints, jointPoints, color, PyKinectV2.JointType_KneeRight, PyKinectV2.JointType_AnkleRight)
        self.draw_body_bone(joints, jointPoints, color, PyKinectV2.JointType_AnkleRight, PyKinectV2.JointType_FootRight)

        # Left Leg
        self.draw_body_bone(joints, jointPoints, color, PyKinectV2.JointType_HipLeft, PyKinectV2.JointType_KneeLeft)
        self.draw_body_bone(joints, jointPoints, color, PyKinectV2.JointType_KneeLeft, PyKinectV2.JointType_AnkleLeft)
        self.draw_body_bone(joints, jointPoints, color, PyKinectV2.JointType_AnkleLeft, PyKinectV2.JointType_FootLeft)
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

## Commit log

2018-11-11 added two testing files for dc and stepper motors
2018-11-29 three motors tested
2018-12-06 added gripper control, improved modularity
2018-12-07 wireless control implemented, move left and right motions implemented
2018-12-07 moveLeft and moveRight motor speed bug fix
    [progress_2.ino]
2018-12-11 added presentation files
    [Untitled Sketch.fzz]
